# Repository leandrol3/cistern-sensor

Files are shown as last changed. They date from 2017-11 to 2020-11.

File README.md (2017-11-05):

# Cistern-sensor

A sensor system to control water volume

## Getting Started

These instructions will get you a copy of the project up and running on your local machine for development and testing purposes. See deployment for notes on how to deploy the project on a live system.

### Prerequisites

- Library NewPing.h Get the lastest version here [github](https://github.com/PaulStoffregen/NewPing.git)

- Arduino (UNO, Mega, Nano, etc)

- HC-SR04 Ultrasonic Sensor



- LED Bargraph with 10 LEDs



- 10 resistors from 100 to 470 ohms

### Installing

Change the height of your cistern at constants EMPTY and FULL
In this case we have 1,70m when it is empty and 10 cm when it is full

```
#define EMPTY 170 // Height to measure the capacity when is empty in centimeters
#define FULL 10 // Height to measure the capacity when is full in centimeters

```

I used 13 and 12 pin to send and receive from ultrasonic sensor and define the max distance using 2,00 meters
```

#define TRIGGER_PIN  13  // Arduino pin tied to trigger pin on the ultrasonic sensor.
#define ECHO_PIN     12  // Arduino pin tied to echo pin on the ultrasonic sensor.
#define MAX_DISTANCE 200 // Maximum distance we want to ping for (in centimeters). Maximum sensor distance is rated at 400-500cm.

```

## Versioning

We use [SemVer](http://semver.org/) for versioning. For the versions available, see the [tags on this repository](https://github.com/your/project/tags). 

## Authors

* **Leandro Lopes** - *Initial work* - [LeLopes](https://github.com/leandrol3/)

## License

This project is licensed under the MIT License - see the [LICENSE.md](LICENSE.md) file for details

## Acknowledgments

* Now we can control our water volume in a cheap way ;)

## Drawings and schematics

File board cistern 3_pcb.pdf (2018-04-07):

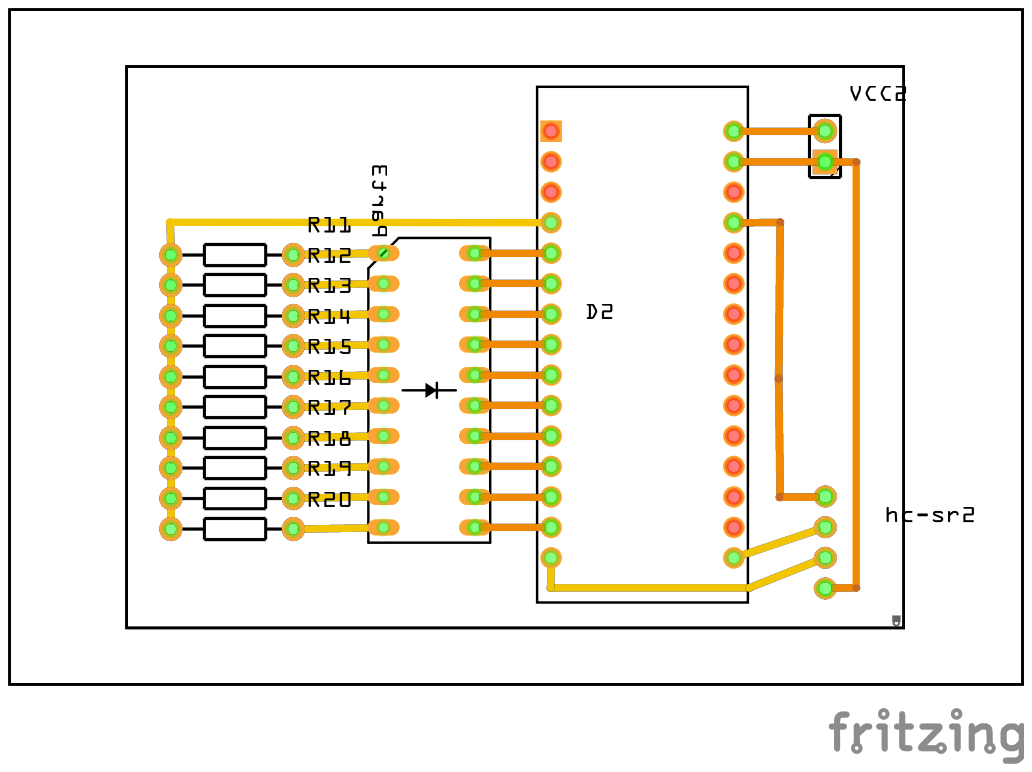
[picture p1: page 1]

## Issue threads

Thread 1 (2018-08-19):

Problema com a solda da placa do Arduino

leandrol3, 2018-08-19:
Ao testar os leds indicadores um não acendia.
Ao checar item por item foi constatado que o problema estava no contato com a placa Arduino Nano na porta D5
Solda resolvida, tudo funcionou ! 💯

Closed 2020-11-07.

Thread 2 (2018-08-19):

Problema ao conectar a placa na fonte

leandrol3, 2018-08-19:
O sensor não funciona ao conectar a alimentação da fonte

Com a alimentação do computador funciona OK, ao conectar com a fonte o sensor para de funcionar

Referencia sobre problema de GND
**Adicionar o código abaixo para resolver o problema de conexão na fonte**
http://mc-computing.com/Hardware_Platforms/Arduino/HC-SR04_Ultrasonic_Sensor.html

Como corrigir erros de retorno do sensor
http://therandomlab.blogspot.com/2015/05/repair-and-solve-faulty-hc-sr04.html

Como melhorar a performance do sensor
https://www.intorobotics.com/8-tutorials-to-solve-problems-and-improve-the-performance-of-hc-sr04/

Referencia técnica do sensor
https://cdn.sparkfun.com/datasheets/Sensors/Proximity/HCSR04.pdf

Cisterna Map Values
https://docs.google.com/spreadsheets/d/11E7Fzz3W5mpgUeoUOo2_2TkWjC35LzJmR4PRvThyd40/edit#gid=0

leandrol3, 2020-11-07:
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

Utilizando uma fonte de 9V conectada no GND e Vcc diretamente na protoboard funcionou normalmente.

A alimentação que não funcionava era utilizando um conector USB e uma pequena fonte de celular de 5V, por esse motivo não funcionava

Closed 2020-11-07.

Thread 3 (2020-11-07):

Projeto Encerrado e Lições Aprendidas

leandrol3, 2020-11-07:
O cabo manga passado de 4 vias tinha 4 metros e não chegava sinal ao ser conectado ao Arduino

O sensor HC-SR04 não resistiu o ambiente úmido da cisterna e se deteriorou depois de 2 anos.
A distância que ficava da água quando a cisterna estava cheia era de aproximadamente 8 centímetros.
O sensor foi encontrado bem molhado e com sinais de ferrugem.
Os contatos estavam desgastados e zinabrados, não funcionou ao ser retirado conectando ao protoboard.

Lições aprendidas:
- Após a passagem do cabo de 4 vias, testar se estava passando corrente antes de fechar a cisterna
- Procurar um sensor que seja resistente a ambiente úmido

Closed 2020-11-07.

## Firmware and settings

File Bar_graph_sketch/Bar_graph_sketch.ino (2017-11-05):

const int qtdeLEDs = 10;
const int pinosLEDs[] = {2,3,4,5,6,7,8,9,10,11};
//const int pinoPotenc = 0;
//int potenciometro = 0;
//int bargraph = 0;
void setup() {
 // int i;
 // for (int i=0; i<=qtdeLEDs; i++) {
    pinMode(2, OUTPUT);
    pinMode(3, OUTPUT);
    pinMode(4, OUTPUT);
    pinMode(5, OUTPUT);
    pinMode(6, OUTPUT);
    pinMode(7, OUTPUT);
    pinMode(8, OUTPUT);
    pinMode(9, OUTPUT);
    pinMode(10, OUTPUT);    
    pinMode(11, OUTPUT);
    Serial.begin(115200); // Open serial monitor at 115200 baud to see ping results.


//  }
}
void loop() {
  
   digitalWrite(2, HIGH);
   digitalWrite(3, HIGH);
   digitalWrite(4, HIGH);
   digitalWrite(5, HIGH);
   digitalWrite(6, HIGH);
   digitalWrite(7, HIGH);
   digitalWrite(8, HIGH);
   digitalWrite(9, HIGH);
   digitalWrite(10, HIGH);
   digitalWrite(11, HIGH);
  
  //potenciometro = analogRead(pinoPotenc);
 // bargraph = map(potenciometro,0,1023,0,10);
  //for (int i=0; i<=qtdeLEDs; i++) {
  Serial.print("Acesso");

    delay(250); 
//    if (i < 9) {
//    }
   // else {
     // digitalWrite(pinosLEDs[i],LOW);
 //   }
  //}
}

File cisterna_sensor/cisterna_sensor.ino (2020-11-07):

// ---------------------------------------------------------------------------
// Cistern Sensor - Leandro Lopes - 05/Nov/2017
// Update - 7/Nov/2020
// Version 1.0
// ---------------------------------------------------------------------------

#include <NewPing.h> //Library to use ultrasonic sensor

#define TRIGGER_PIN  13  // Arduino pin tied to trigger pin on the ultrasonic sensor.
#define ECHO_PIN     12  // Arduino pin tied to echo pin on the ultrasonic sensor.
#define MAX_DISTANCE 500 // Maximum distance we want to ping for (in centimeters). Maximum sensor distance is rated at 400-500cm.

#define EMPTY 154 // Height to measure the capacity when is empty in centimeters
#define FULL 4 // Height to measure the capacity when is full in centimeters

NewPing sonar(TRIGGER_PIN, ECHO_PIN, MAX_DISTANCE); // NewPing setup of pins and maximum distance.

void setup() {
  
  Serial.begin(57600); // Open serial monitor at 115200 baud to see ping results.
  
  //Determines all ports to Bar graph from 2 to 12
  for (int i = 2; i < 12; i++) {
    pinMode(i, OUTPUT);
  }
}

void loop() {
  int distance;  //load distance from ultrasonic sensor
  int level; //level of bar graph to print between 154 (max height - empty) to 4 (min height - full)
  distance = sonar.ping_cm();
  delay(250);                     // Wait 150ms between pings (about 8 pings/sec). 29ms should be the shortest delay between pings.
  //If debug on
//  distance = 10;
  Serial.print("Distance: "); // Send ping, get distance in cm and print result (0 = outside set distance range)
  Serial.println(distance); // Send ping, get distance in cm and print result (0 = outside set distance range)

  level = map(distance, FULL, EMPTY, 0, 10);  //Maps distance to level from 0 to 10
  if (distance != 0) {   // Somente ativa se o valor for diferente de 0 
//    If debug on
    Serial.print("Ping: ");
    Serial.print(distance); // Send ping, get distance in cm and print result (0 = outside set distance range)
    Serial.println("cm");
    Serial.println(level);
    setbargraph(level);
  } 
}
void setbargraph(int level) {
  //Acende somente ao nivel passado na variavel
  for (int i = 0; i < 11; i++) {
     if (i < level) {
        digitalWrite(i+2, LOW);
     }
     else {
        digitalWrite(i+2, HIGH);
     }
  }
}

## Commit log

2017-11-06 Added Fritz documents
    [pcb_cistern_sensor.fzz]
2017-11-16 add: fritzing file
    [pcb_cistern_sensor.fzz]
2018-04-07 Add: files from fritzing
    [pcb_cistern_sensor_v2.fzz]
2018-08-19 New frizting- reducao do tamnanho da placa
    [pcb_cistern_sensor_v3.fzz]
